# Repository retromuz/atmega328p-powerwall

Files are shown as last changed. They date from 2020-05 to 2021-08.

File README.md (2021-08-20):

# ATMEGA328P-powerwall

This project is intended to be used with below two projects.
1. https://github.com/retromuz/esp32-bms-monitor.git
2. https://github.com/retromuz/esp8266-powerwall.git

This is the brain behind the DC to DC boost converter that charges 14S Li-Ion battery system. It also does MPPT function. Acts as an I²C slave for ESP8266 master.

ATMEGA328P drives boost converter at 125kHz. Duty cycle is varied at real-time to maintain output voltage within 14S battery charge limits. It also adjusts the input voltage (from 48V solar panels) in order to extract maximum energy during the day.

V2 board adds additional functionality on top of function V1 board. These are:
1. Input surge protection (from transient spikes due to lightning etc)
2. Better voltage regulation
3. Better filtering
4. Even more efficient conversion due to higher current carrying capacity of power traces
5. Removed unwanted DACs from design
6. Output current sensing
7. Atmega328p on-board MPPT (works even without ESP8266)

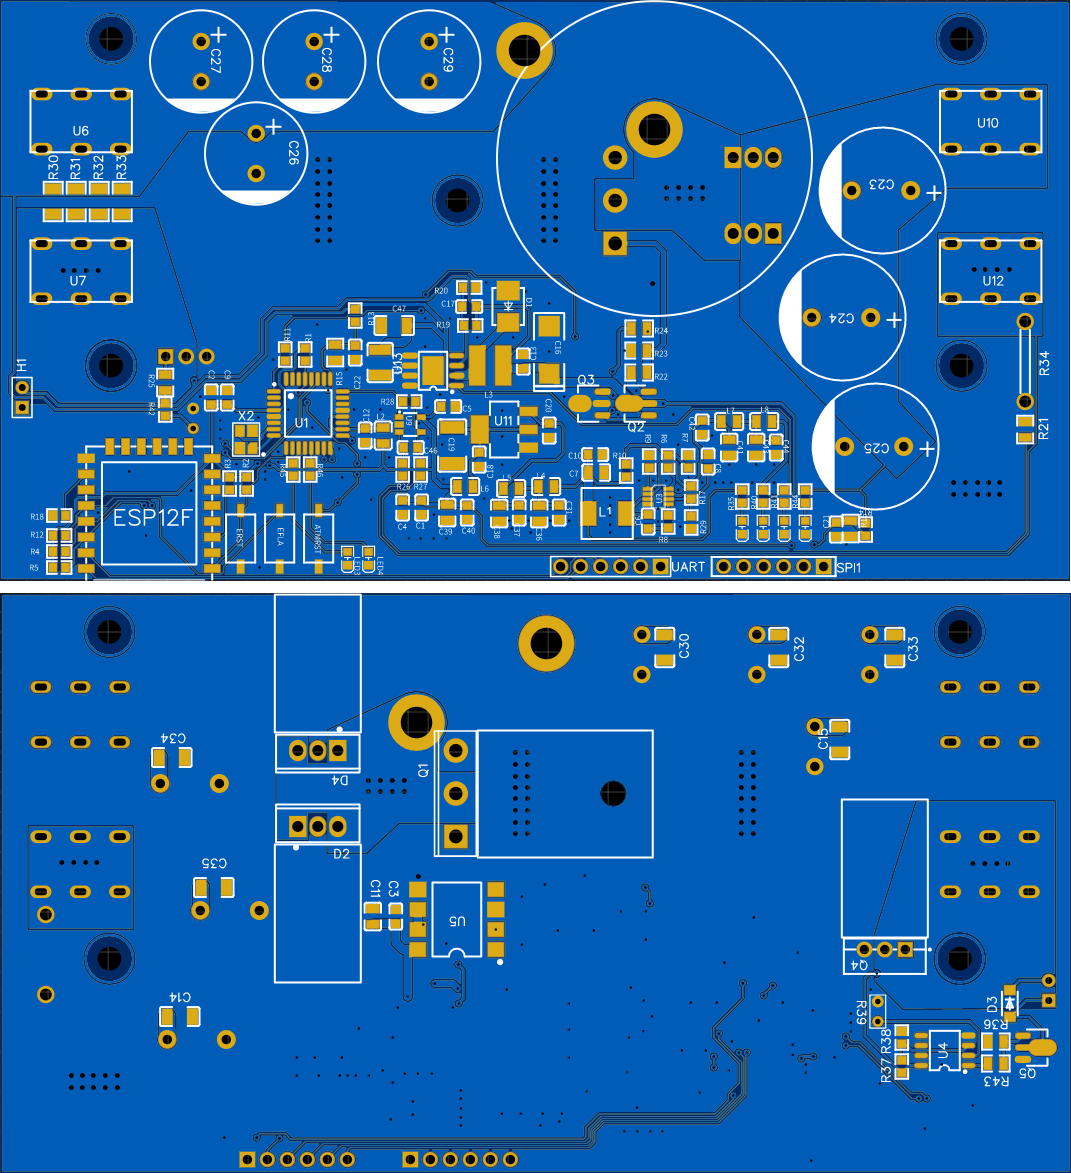
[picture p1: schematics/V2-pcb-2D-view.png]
PCB

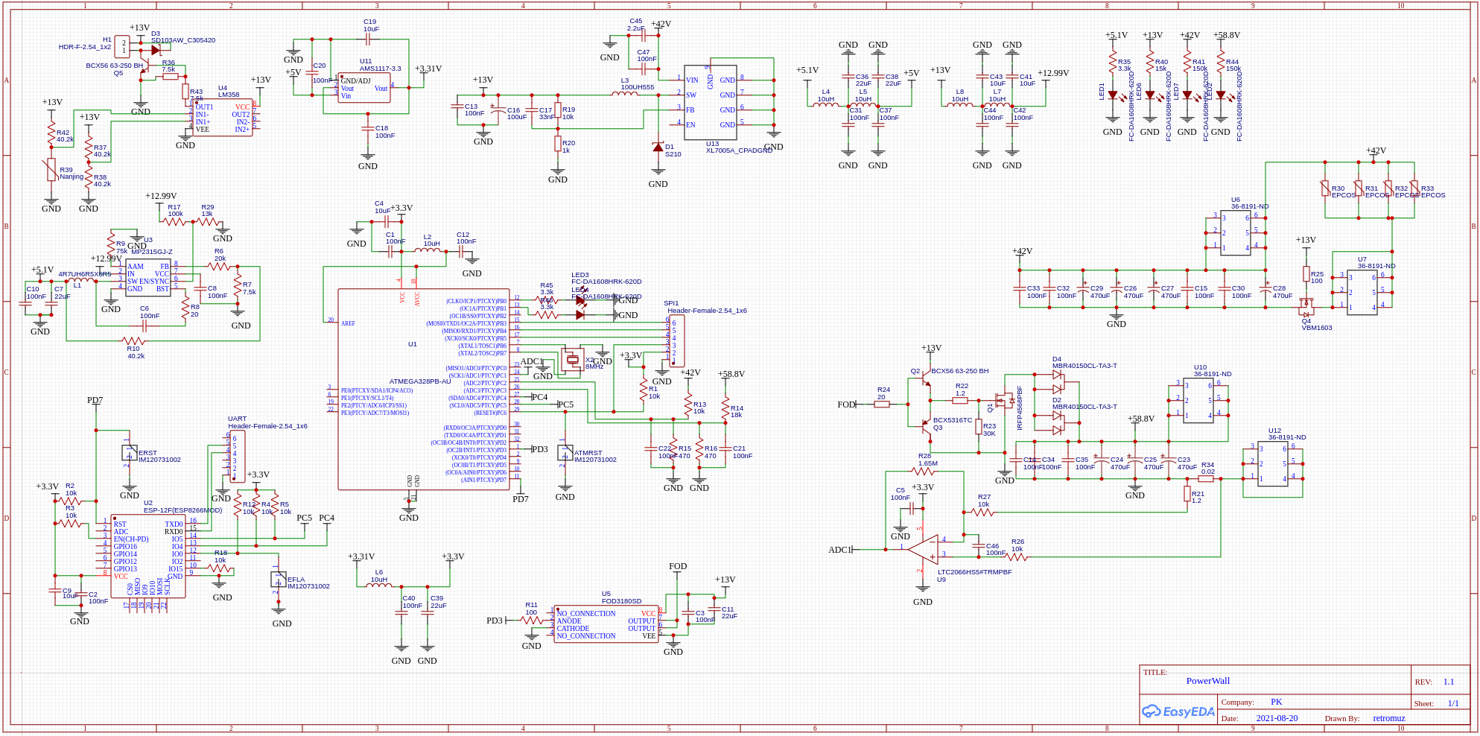
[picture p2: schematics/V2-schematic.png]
Schematics


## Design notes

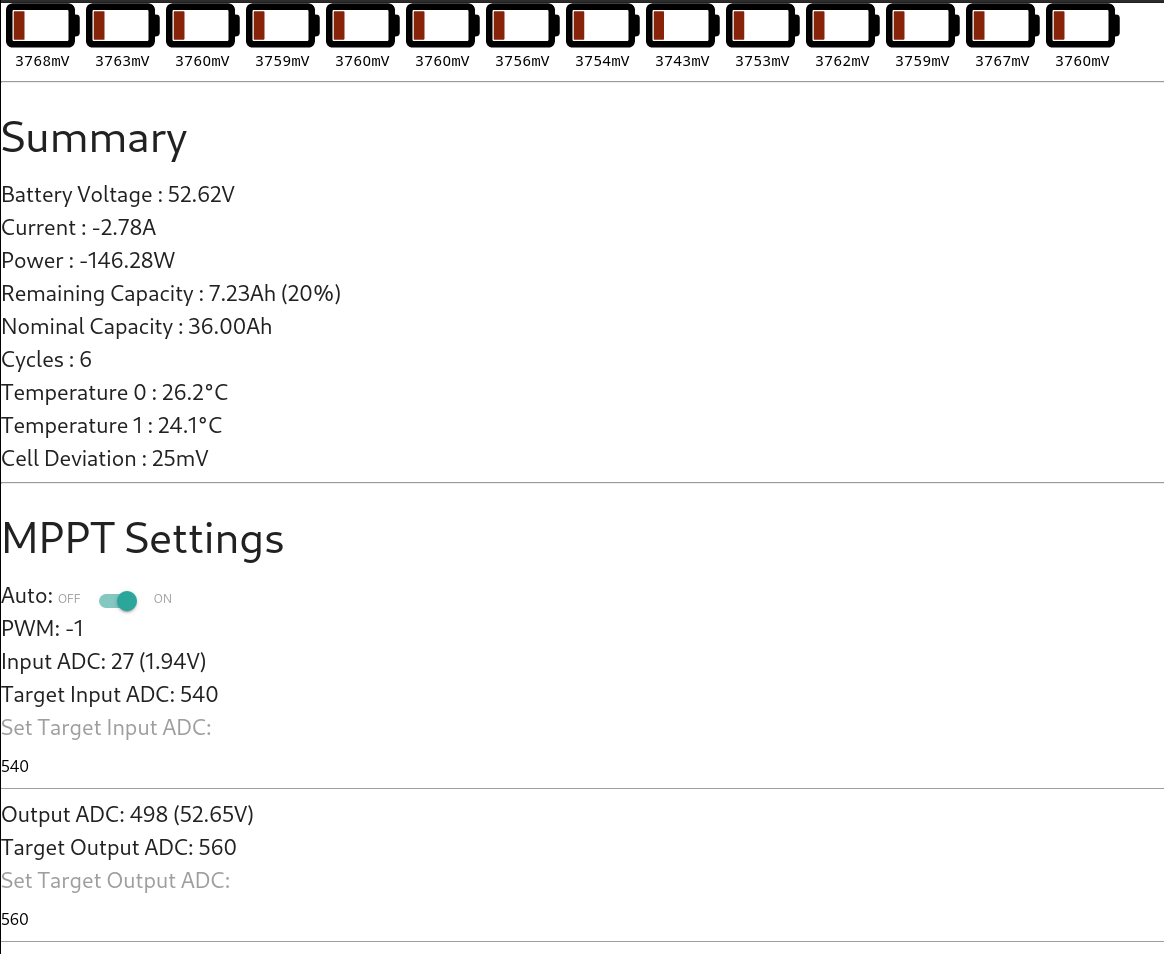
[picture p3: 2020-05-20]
photos/powerwall-web-ui-discharging.png

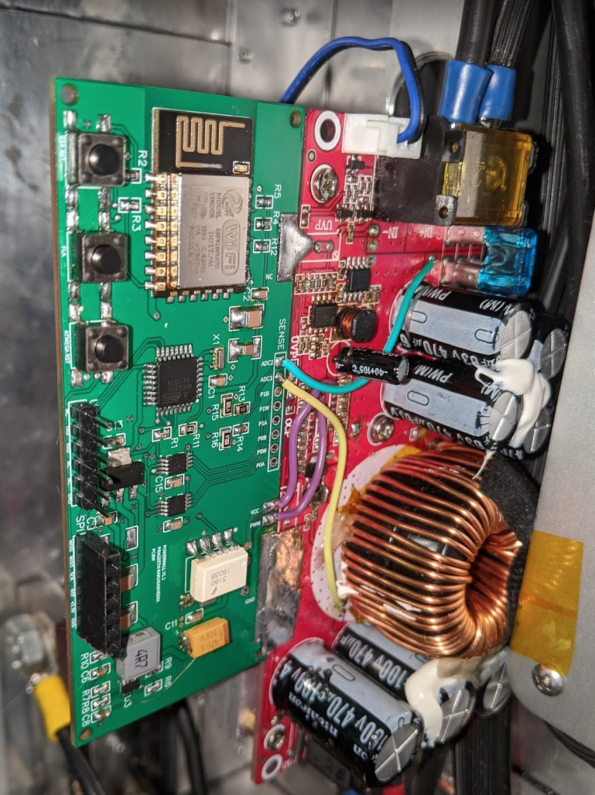
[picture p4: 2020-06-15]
photos/mod-boost-converter-pcb.png

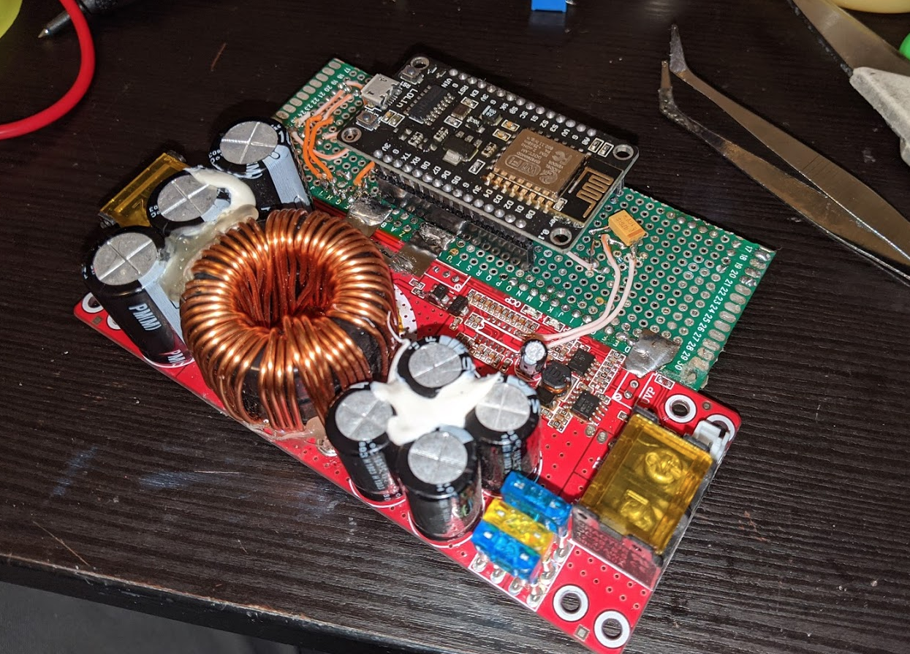
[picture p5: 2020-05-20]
photos/mod-boost-converter-esp8266-shown.png

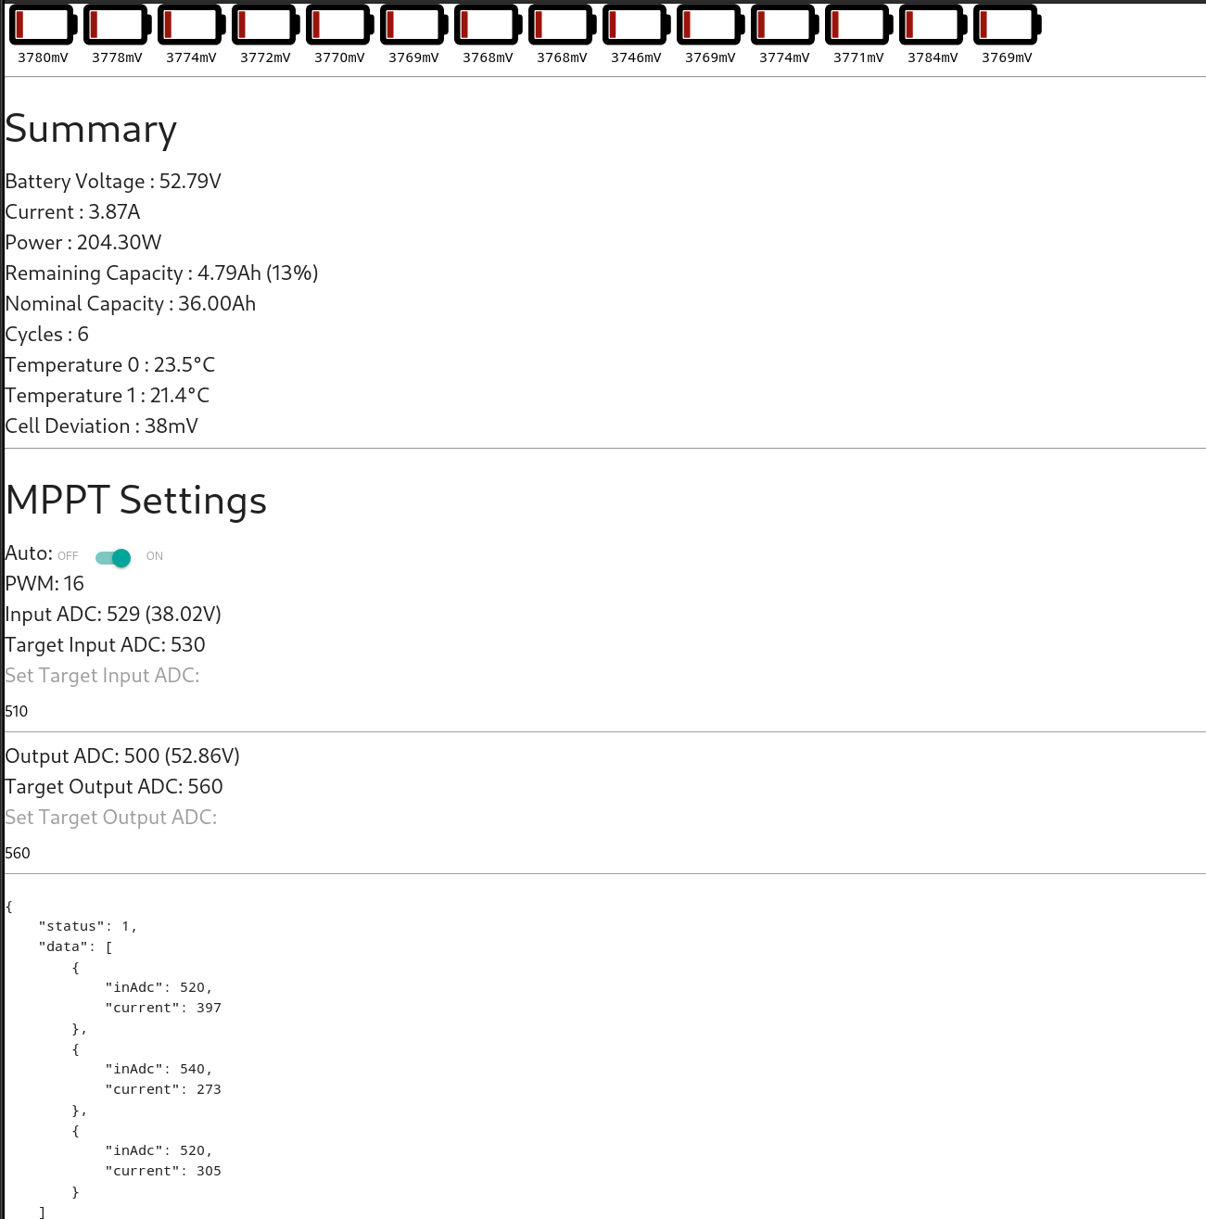
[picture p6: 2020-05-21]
photos/powerwall-web-ui-discharging2.png

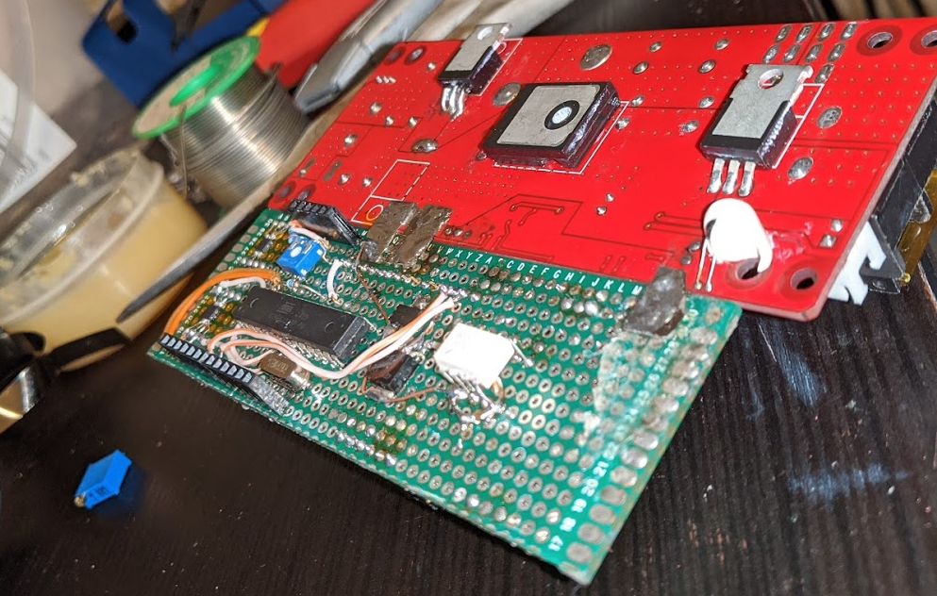
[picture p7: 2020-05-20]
photos/mod-boost-converter-atmega328p-shown.png

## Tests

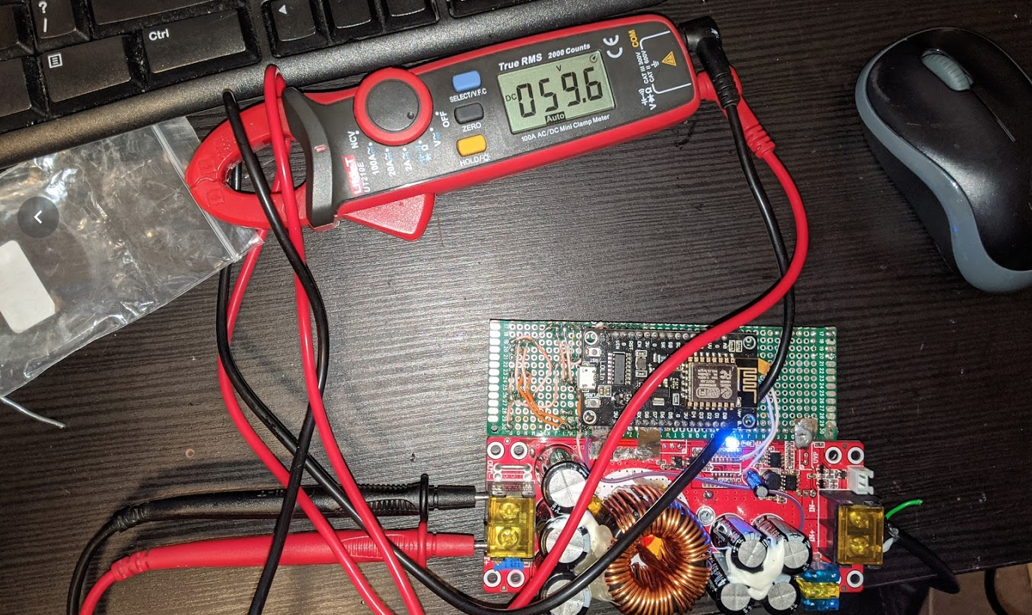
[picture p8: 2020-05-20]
photos/mod-boost-converter-output-voltage-calibration.png

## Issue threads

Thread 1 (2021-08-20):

Boost converter "connections"

ortegafernando, 2021-08-20:
Hi, thanks a lot for this great project, but I can see where I could check which are the connections (where and how) that you have make to the boost dc converter board.

Are you using arduino's pwm to operate directly mosfet?
Or are you using arduino's pwm to inject some current to any feedback pin or "comparator input pin" ?

Thanks.

retromuz, 2021-08-20:
Please refer to ADC2 and ADC3. These pins from ATMEGA328P. Atmega monitors these pins in real-time to control PWM output that goes into FOD3180 optocoupler. Optocoupler then feeds to the NPN, PNP transistor pair in the boost converter board directly. This controls the power MOSFET. You should be able to see the simple algorithm that decides what pulse width to output in the void loop() function.

In a later PCB version, I implemented ADC1 to read current output as well so that I can montor output power to the battery as well. This version is a single PCB board that is almost as same size as the board sold on eBay that has no MPPT function.

ortegafernando, 2021-08-20:
Hi, could you upload several photos to see exaclly in your pcb board where you have solder wires to the dc converter board? Thanks

retromuz, 2021-08-20:
@ortegafernando see this photo where I marked the specific points on the eBay boost converter. https://github.com/retromuz/atmega328p-powerwall/blob/master/photos/V1-solder-points-guide.png

BTW, I now have updated the code to V2. This includes firmware that does MPPT on ATMEGA itself and V2 schematics. If you print this board, you can get everything on a single board. No more fussing with wires. This gives you current sensing as well. See [README.md](https://github.com/retromuz/atmega328p-powerwall/blob/master/README.md) for upgraded circuit.

retromuz, 2021-08-20:
@ortegafernando anymore questions?

ortegafernando, 2021-08-23:
I will check V2 of course. If I print the pcb board I understand that I still need the boost converter, isn't it? So ... how your new v2 design has to be connected to the dc dc boost converter? which pcb pin with which boost converter pin? Thanks a lot. (may be you can update readme or made a "how to connect hardware.md".

retromuz, 2021-08-23:
V2 board combines the boost converter with the second board (controller) into a **single board**. Then you can transfer necessary components from boost converter into the V2 board. This stops you from messing around sensor and controller pins because they are built into V2 board to match with hardware and firmware.

retromuz, 2021-08-28:
1. There is no link to buy it yet. But I have a couple of blank unused boards (I only needed one but printed ~10). Where are you located? BTW you can easily get these printed from jlcpcb.com or any other pcb supplier for really cheap.
2. Digital pots were not-in-use in V1 board. As V1 was a prototype this is expected. You can ignore these.

ortegafernando, 2021-08-28:
> 1. There is no link to buy it yet. But I have a couple of blank unused boards (I only needed one but printed ~10). Where are you located? BTW you can easily get these printed from jlcpcb.com or any other pcb supplier for really cheap.
> 2. Digital pots were not-in-use in V1 board. As V1 was a prototype this is expected. You can ignore these.

Sirry, I thought that your V1 was a "chinise booster module bought in ebay or aliexpress" in which you solder a few pins to your arduino.
I was asking for the link of that "ali/ebay" booster module.

retromuz, 2021-08-28:
1. V1 is the daugter board I initially came up at first prototype stage. If you want to buy the booster module, you could do a Google search for "1500w dc-dc boost converter" and go from there.

ortegafernando, 2022-01-02:
Hi retromuz, I will try again to learn about this project this new year.
I am thinking of two possibilities not to do so much savage in the original dcdc boost converter (in my case, 1200w version).

1. Inject a signal from an ESP8266 or ATMEGA into Pin 1 of TL494 becuase it is responsible of "output voltage".  (I get managed to do something similar with a SZKB07 step down dc dc converter). This is very easy to solder, as we only need to connect a PWM output from our "brain IC" to the pin 1 of the TL494 in boost converter module.
2. Directly, use the PWM output of our "brain IC" to the pin 9 of the TL494 and getting of the TL494, so we can directly control the PWM signal of the booster board's transistors that control the output mosfet.

I will prefer the option 1, much more easier. Do you think if it will work?

Thanks.

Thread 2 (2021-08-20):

please see this: https://github.com/retromuz/atmega328p-powerwall/issues/1 and close this one an reopen the other one. THAKS

ortegafernando, 2021-08-20:
please see this: https://github.com/retromuz/atmega328p-powerwall/issues/1 and close this one an reopen the other one. THAKS

retromuz, 2021-08-20:
Reopened #1

Closed 2021-08-20.

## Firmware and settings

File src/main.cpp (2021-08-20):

/*********************************************************************
 *********************************************************************/

#include "main.h"

volatile int pwm = MIN_PWM;
volatile unsigned int targetInput = MAX_TARGET_INPUT;
volatile unsigned int targetOutput = CHARGE_STOP_VOLTAGE_ADC;

volatile byte requestedAddr = I2C_CMD_DEFAULT;
volatile unsigned int a3 = 0; // output voltage adc
volatile unsigned int a2 = 0; // input voltage adc
volatile unsigned int a1 = 0; // output current adc

volatile unsigned long input_current = 0;
volatile unsigned long output_current = 0;

volatile unsigned int loops = 0;
volatile unsigned int espRstLoops = 0;
volatile byte espResetting = 0;

volatile bool stopCharging = false;
volatile bool noMppt = false;
volatile bool mppt = true;
volatile bool initMppt = true;
MPPTData mpptData;

void setup() {
//	Serial.begin(115200);
	DDRC &= (1 << PC3); // ADC3 as input (output voltage measurement)
	DDRC &= (1 << PC2); // ADC2 as input (input voltage measurement)
	DDRC &= (1 << PC1); // ADC2 as input (output current sense)

	DDRD |= (1 << PD3); // PWM output
	TCCR2A = _BV(COM2A1) | _BV(COM2B1) | _BV(WGM21) | _BV(WGM20);
	TCCR2B = _BV(WGM22) | _BV(CS20); // CS21:clk/8 32.25kHz, CS20:no prescaling 250kHz
	setPWM();  // 160 clock periods = 10us per cycle
	OCR2A = 63;

	DDRD |= (1 << PD7); // ESP reset as output
	PORTD |= (1 << PD7); // turn on so that esp8266 does not reset.

	DDRB |= (1 << PB0); // LED 3
	DDRB |= (1 << PB1); // LED 4

	Wire.setClock(I2C_CLOCK);
	Wire.begin(I2C_ADDR);
	Wire.onReceive(i2cReceive);
	Wire.onRequest(i2cSend);
	mpptData.status = 0;
}

void loop() {

	regulate();

	PORTB &= ~(1 << PB0);

	if (espResetting && espRstLoops > 4) {
		PORTD |= (1 << PD7); // reset esp high
		PORTB &= ~(1 << PB1); // turn off LED4
		espResetting = 0;
		espRstLoops = 0;
	} else if (espRstLoops > ESP_RESET_LOOPS_COUNT_THRESHOLD) {
		espRstLoops = 0;
		resetESP8266();
	}

	if (!mppt && loops % (LOOPS_PER_SECOND * 60l * 10l) == 0) {
		mppt = true;
	}

	if (mppt) {
		mpptScan(initMppt ? 100 : 20);
	}

	loops++;
	espRstLoops++;
}

void regulate() {
	unsigned int a3x = precisionAnalogRead(A3); // output voltage adc
	a2 = precisionAnalogRead(A2); // input voltage adc
	a1 = precisionAnalogRead(A1); // output current adc
	a3 = a3x - (a1 * 7 / 410);

	output_current = (unsigned long) (a1 * OUTPUT_CURRENT_ADC_TO_MA_RATIO); // mA
	unsigned long output_power = (unsigned long) (output_current
			* ((58.8 * a3) / 420)); // mW
	input_current = output_power / (a2 * 40 / 560); // mA

	// cater for output sense voltage drift due to charge current

	if (stopCharging) {
		targetInput = MAX_TARGET_INPUT;
	}

	if (a2 < MIN_TARGET_INPUT || input_current > MAX_INPUT_CURRENT) {
		decPWM();
	} else {
		if (a3 > targetOutput || a2 < targetInput
				|| ((a3 > CHARGE_STOP_VOLTAGE_ADC - 2)
						&& output_current > MAX_OUTPUT_CURRENT_AT_SATURATION)
				|| ((a3 > CHARGE_STOP_VOLTAGE_ADC - 1)
						&& output_current > MAX_OUTPUT_CURRENT_AT_SATURATION / 2)) {
			decPWM();
		} else if (a3 < targetOutput && a2 > targetInput) {
			incPWM();
		}
	}

	if (a3 > CHARGE_STOP_VOLTAGE_ADC && a1 < CHAGE_STOP_CURRENT_ADC) {
		stopCharging = true;
	}

	if (stopCharging && (a3 < CHARGE_RESTART_VOLTAGE_ADC)) {
		stopCharging = false;
		targetInput = TARGET_INPUT;
		initMppt = true;
		mppt = true;
	}

}

void mpptScan(unsigned int statusesToCapture) {
	if (noMppt) {
		return;
	}
	if (mpptData.status == statusesToCapture) {
		mpptData.status = 0;
		mpptAnalyze(statusesToCapture);
	} else if (loops % MPPT_STEP_DELAY_LOOPS == 0) {
		if (mpptData.status == 0 && statusesToCapture == 20) {
			unsigned int targetIn = targetInput + (MPPT_STEP * 10);
			if (targetIn >= MIN_TARGET_INPUT && targetIn <= MAX_TARGET_INPUT) {
				targetInput = targetIn;
			}
		}
		regulate();
		MPPTEntry entry;
		entry.inAdc = targetInput;
		entry.current = a1;
		mpptData.data[mpptData.status] = entry;
		mpptData.status++;
		regulate();
		unsigned int targetIn = targetInput - MPPT_STEP;
		if (targetIn >= MIN_TARGET_INPUT && targetIn <= MAX_TARGET_INPUT) {
			targetInput = targetIn;
		}
	}
}

void mpptAnalyze(unsigned int statusesToCapture) {
	if (noMppt) {
		return;
	}
	unsigned int max_current = 0;
	unsigned int max_yield_inAdc = 0;
	for (unsigned int x = 0; x < statusesToCapture; x++) {
		regulate();
		MPPTEntry entry = mpptData.data[x];
		if (entry.current >= max_current) {
			max_current = entry.current;
			max_yield_inAdc = entry.inAdc;
		}
	}
	if (max_yield_inAdc >= MIN_TARGET_INPUT
			&& max_yield_inAdc <= MAX_TARGET_INPUT) {
		targetInput = max_yield_inAdc;
	}
	mppt = false;
	initMppt = false;
}

void resetESP8266() {
	if (!espResetting) {
		PORTB |= (1 << PB1); // turn on LED4
		PORTD &= ~(1 << PD7); // reset esp low
		espResetting = 1;
	}
}

int precisionAnalogRead(uint8_t PORT) {
	uint8_t x = 0;
	int v = 0;
	while (x++ < PRECISION_ANALOG_READ_COUNT) {
		v = v + analogRead(PORT);
	}
	return v / PRECISION_ANALOG_READ_COUNT;
}

void i2cReceive(int k) {
	espRstLoops = 0;
	PORTB |= (1 << PB0);
	byte addr = Wire.read();
	if (I2C_CMD_WRITE_TARGET_INPUT_ADC_VAL == addr) {
		int n = ((byte) Wire.read()) | ((byte) Wire.read()) << 8;
		if (!stopCharging && n >= MIN_TARGET_INPUT && n <= MAX_TARGET_INPUT) {
			targetInput = n;
		}
	} else if (I2C_CMD_WRITE_TARGET_OUTPUT_ADC_VAL == addr) {
		int n = ((byte) Wire.read()) | ((byte) Wire.read()) << 8;
		if (n >= MIN_TARGET_OUTPUT && n <= MAX_TARGET_OUTPUT) {
			targetOutput = n;
		}
	} else if (I2C_CMD_WRITE_NO_MPPT == addr) {
		int n = ((byte) Wire.read()) | ((byte) Wire.read()) << 8;
		noMppt = (n == 1);
	} else {
		requestedAddr = addr;
	}
}

void i2cSend() {

	if (I2C_CMD_READ_TARGET_INPUT_ADC_VAL == requestedAddr) {
		byte arr[2];
		arr[0] = targetInput & 0xff;
		arr[1] = (targetInput & 0xff00) >> 8;
		Wire.write(arr, 2);
	} else if (I2C_CMD_READ_TARGET_OUTPUT_ADC_VAL == requestedAddr) {
		byte arr[2];
		arr[0] = targetOutput & 0xff;
		arr[1] = (targetOutput & 0xff00) >> 8;
		Wire.write(arr, 2);
	} else if (I2C_CMD_READ_INPUT_ADC_VAL == requestedAddr) {
		byte arr[2];
		arr[0] = a2 & 0xff;
		arr[1] = (a2 & 0xff00) >> 8;
		Wire.write(arr, 2);
	} else if (I2C_CMD_READ_OUTPUT_ADC_VAL == requestedAddr) {
		byte arr[2];
		arr[0] = a3 & 0xff;
		arr[1] = (a3 & 0xff00) >> 8;
		Wire.write(arr, 2);
	} else if (I2C_CMD_READ_OUTPUT_CURRENT_ADC_VAL == requestedAddr) {
		byte arr[2];
		arr[0] = a1 & 0xff;
		arr[1] = (a1 & 0xff00) >> 8;
		Wire.write(arr, 2);
	} else if (I2C_CMD_READ_OUTPUT_CURRENT_ESTIMATE == requestedAddr) {
		byte arr[3];
		arr[0] = output_current & 0xff;
		arr[1] = (output_current & 0xff00) >> 8;
		arr[2] = (output_current & 0xff0000) >> 16;
		Wire.write(arr, 3);
	} else if (I2C_CMD_READ_INPUT_CURRENT_ESTIMATE == requestedAddr) {
		byte arr[3];
		arr[0] = input_current & 0xff;
		arr[1] = (input_current & 0xff00) >> 8;
		arr[2] = (input_current & 0xff0000) >> 16;
		Wire.write(arr, 3);
	} else if (I2C_CMD_READ_MPPT_STATUS == requestedAddr) {
		Wire.write(noMppt ? 0 : 1);
	} else if (I2C_CMD_READ_PWM_VAL == requestedAddr) {
		Wire.write(pwm);
	} else if (I2C_CMD_READ_FREQ == requestedAddr) {
		Wire.write(TCCR2B == (_BV(WGM22) | _BV(CS20)) ? 0 : 1);
	}
	requestedAddr = I2C_CMD_DEFAULT;
}

void incPWM() {
	pwm = pwm < MAX_PWM ? pwm + 1 : pwm;
	setPWM();
}

void decPWM() {
	pwm = pwm > MIN_PWM ? pwm - 1 : pwm;
	setPWM();
}

void setPWM() {
	if (pwm >= MIN_PWM && pwm <= MAX_PWM) {
		if (pwm == -1) {
			DDRD &= ~(1 << PD3); // turn off output to set 0 duty cycle
		} else {
			DDRD |= (1 << PD3);
			OCR2B = pwm;
		}
	}
}

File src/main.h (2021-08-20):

// Only modify this file to include
// - function definitions (prototypes)
// - include files
// - extern variable definitions
// In the appropriate section

#ifndef _POWERWALL_MAIN_H_
#define _POWERWALL_MAIN_H_
#include <avr/io.h>
#include <inttypes.h>
#include <util/delay.h>
#include <stdlib.h>
#include <Arduino.h>
#include <Wire.h>

#define F_CPU  8000000L

#define I2C_ADDR 0b00100010
#define I2C_CLOCK 100000
#define I2C_CMD_WRITE_TARGET_INPUT_ADC_VAL 0
#define I2C_CMD_WRITE_TARGET_OUTPUT_ADC_VAL 4
#define I2C_CMD_READ_TARGET_INPUT_ADC_VAL 1
#define I2C_CMD_READ_TARGET_OUTPUT_ADC_VAL 5
#define I2C_CMD_READ_INPUT_ADC_VAL 2
#define I2C_CMD_READ_OUTPUT_ADC_VAL 3
#define I2C_CMD_READ_PWM_VAL 6
#define I2C_CMD_READ_FREQ 8
#define I2C_CMD_READ_OUTPUT_CURRENT_ADC_VAL 10
#define I2C_CMD_READ_INPUT_CURRENT_ESTIMATE 11
#define I2C_CMD_READ_OUTPUT_CURRENT_ESTIMATE 12
#define I2C_CMD_READ_MPPT_STATUS 13
#define I2C_CMD_WRITE_NO_MPPT 14
#define I2C_CMD_DEFAULT 0xff

#define MIN_TARGET_INPUT 419 // 30V
#define MAX_TARGET_INPUT 700 // 50V
#define MAX_INPUT_CURRENT 30000 // 30A
#define MAX_OUTPUT_CURRENT_AT_SATURATION 5000 // 5A
#define CHAGE_STOP_CURRENT_ADC 1000 / 30 // 1000mA
#define CHARGE_STOP_VOLTAGE_ADC 420 // 416 = 58.2V (4.15V / cell)
#define CHARGE_RESTART_VOLTAGE_ADC 410 // 57.4V (4.1V / cell)
#define TARGET_INPUT 670 // 47.89V

#define OUTPUT_CURRENT_ADC_TO_MA_RATIO 30

#define MIN_TARGET_OUTPUT 200
#define MAX_TARGET_OUTPUT 900

#define TIMER_COUNTER_TOP 63 // 8MHz / 64 -> 125kHz PWM frequency
#define MAX_PWM 56 // 90% duty
#define MIN_PWM -1

#define MPPT_STEP 4
#define MPPT_STEP_DELAY_LOOPS 40

#define PRECISION_ANALOG_READ_COUNT 20
#define LOOPS_PER_SECOND 400
#define ESP_RESET_LOOPS_COUNT_THRESHOLD 8000

#define TIMSK     _SFR_IO8(0x37)

//end of add your includes here
#ifdef __cplusplus
extern "C" {
#endif

typedef struct {
	unsigned int inAdc;
	unsigned int current;
} MPPTEntry;

typedef struct {
	MPPTEntry data[100];
	unsigned int status;
} MPPTData;

void setup();
void loop();
void regulate();
void incPWM();
void decPWM();
void setPWM();
void i2cReceive(int k);
void i2cSend();
int precisionAnalogRead(uint8_t PORT);
void resetESP8266();
void mpptScan(unsigned int statusesToCapture);
void mpptAnalyze(unsigned int statusesToCapture);

#ifdef __cplusplus
} // extern "C"
#endif

//Do not add code below this line
#endif /* _POWERWALL_MAIN_H_ */

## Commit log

2020-05-09 lower frequency PWM
2020-05-19 precision ADC - i2c communication client
2020-05-21 charging on a heavily cloudy day - web ui
2020-05-24 schematics, gerber files
    [PCB_2020-05-24_14-58-45_2020-05-25_04-14-55.pcbdoc]
2020-05-24 Schematics - README
2020-06-15 boost converter pcb image
2020-07-20 MPPT changes
    [BOM_PowerWall2_2020-07-05_23-22-32.csv]
2021-08-20 V2 - Move MPPT function to ATMEGEA, Add PCB design files
    [BOM_PowerWall2_2020-07-05_23-22-32.csv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]
2021-08-20 V1 - solder points guide photo added, readme updated
